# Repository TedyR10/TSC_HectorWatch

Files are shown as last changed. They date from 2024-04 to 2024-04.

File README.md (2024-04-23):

**Name: Theodor-Ioan Rolea**

**Group: 333CA**

# Hector Watch

### Description
* This project focuses on creating a smart watch from the ground up using
certain parts provided by the TSC Team. The smart watch has the following
features: 6 axis intertial unit, haptic motor driver, LiPo battery,
USB C, 1.28 inch 240x240p LCD display.

***

### Steps to developing the watch
* 1. Electrical scheme implementation
* 2. PCB design

***

### Electrical scheme implementation
* The provided electrical scheme was implemented using Fusion 360's schematic feature,
then the components were linked to the PCB design.

***

### PCB design
* The PCB design was done using Fusion 360's PCB design feature. The routes were done
manually, routing with 0.3mm for the power lines and 0.127mm for the signal lines. I
decided not to place the test pads in a specific location, but rather place them in
a way that would allow me to fully connect the components.

***

### Final thoughts
* The project was a great experience, as it allowed me to learn how to use Fusion 360's
schematic and PCB design features. I also learned how to properly route the PCB and
how to properly place the components. I am looking forward to the next project.

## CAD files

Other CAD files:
FullDesign_RoleaTheodorIoan_333CA.f3z

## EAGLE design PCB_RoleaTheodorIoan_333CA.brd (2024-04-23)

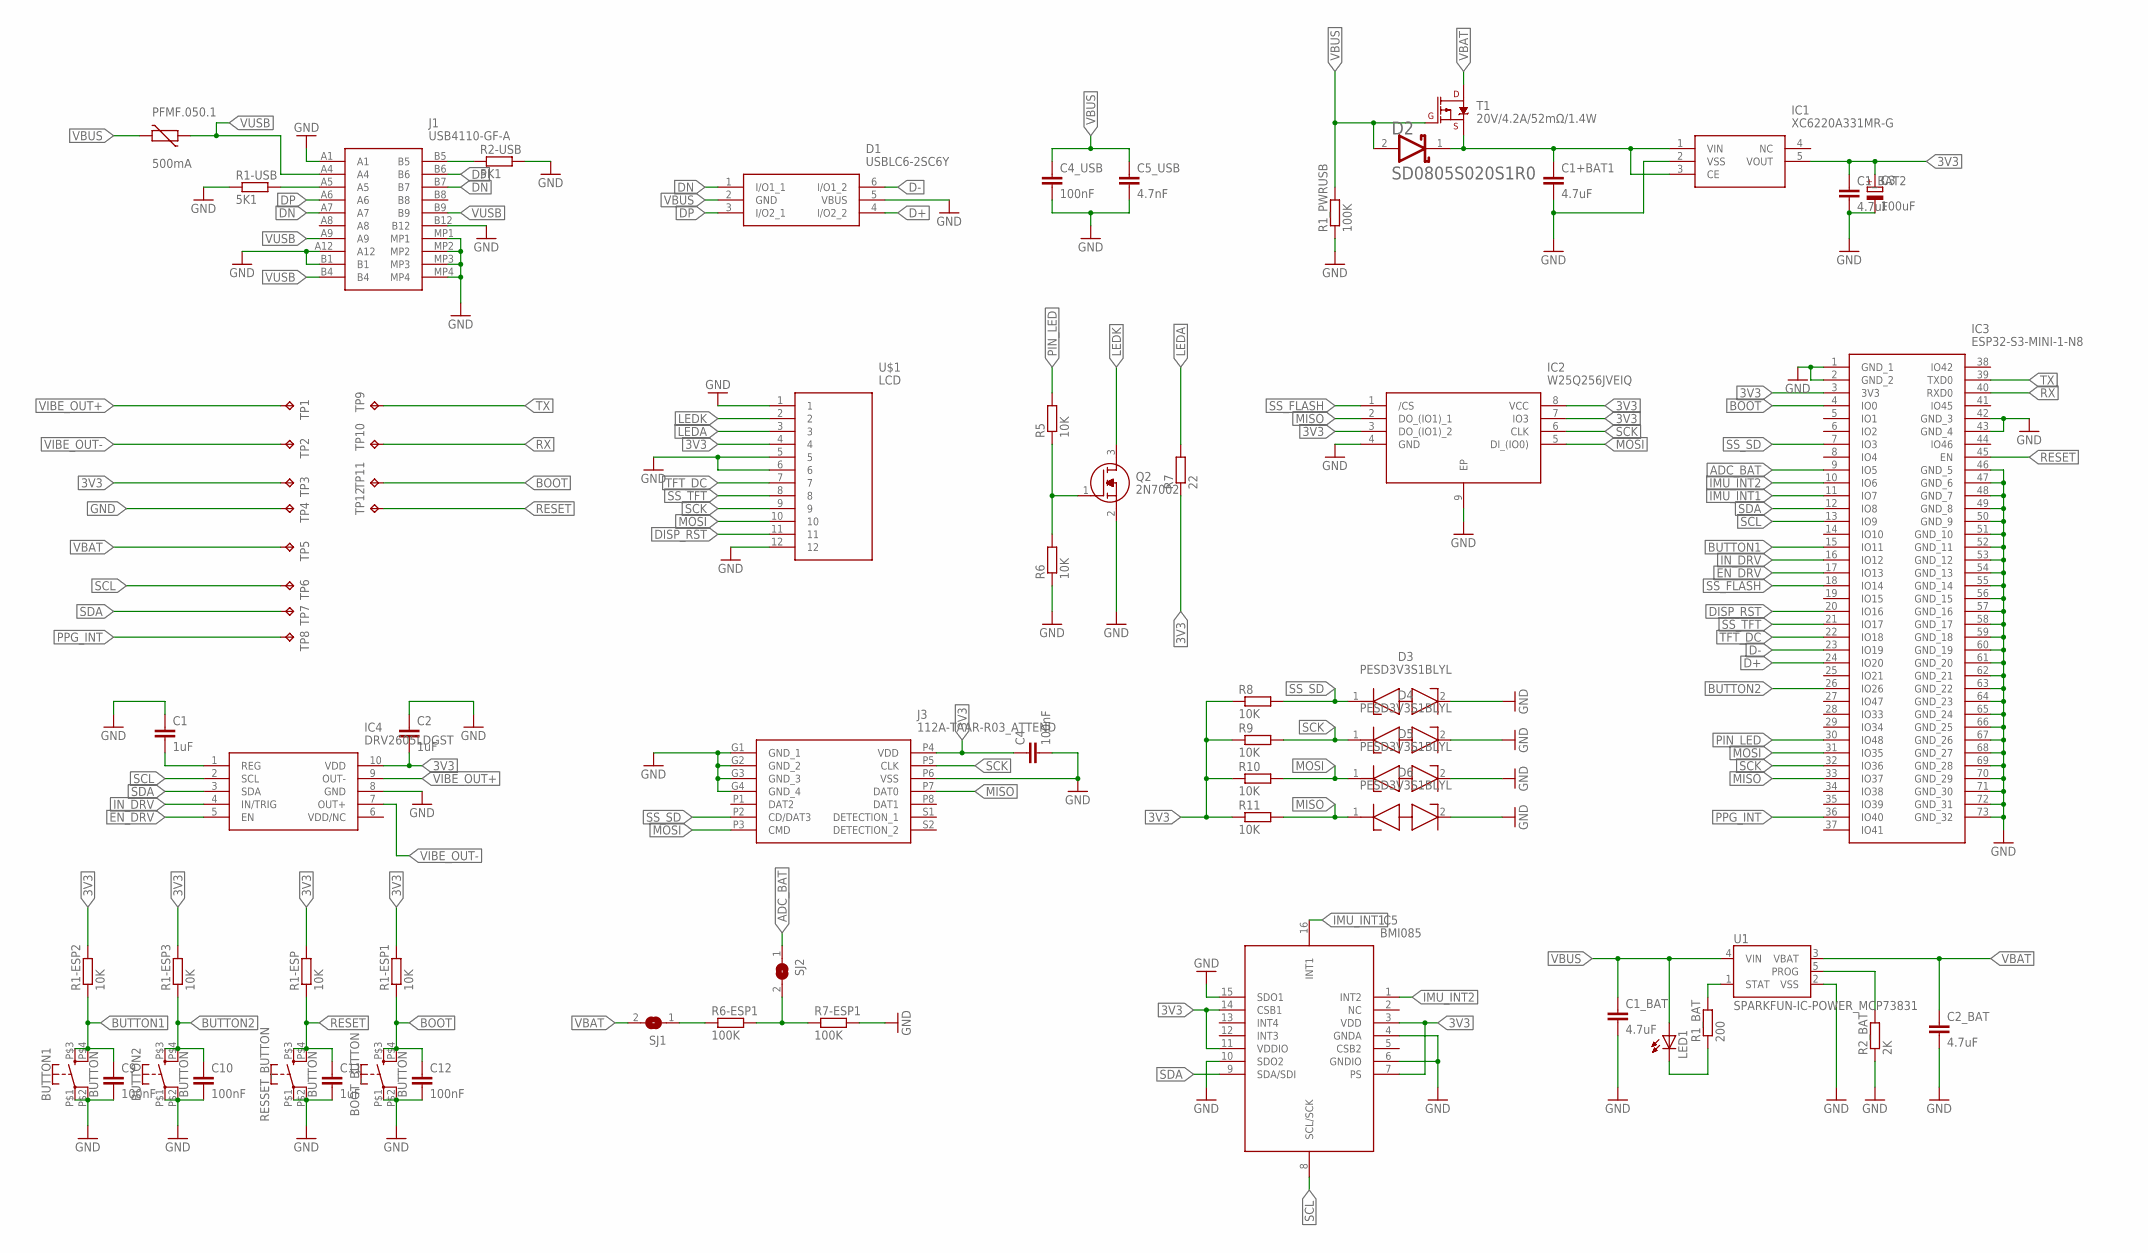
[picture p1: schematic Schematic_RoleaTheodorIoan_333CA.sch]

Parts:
BOOT_BUTTON: BUTTON
BUTTON1, BUTTON2: BUTTON
C1, C2, C11: 1uF; EAGLE-LTSPICE_C0402
C1+BAT1, C1_BAT, C1_BAT2, C2_BAT: 4.7uF; RCL_C0603
C3: 100uF; CT3528
C4, C9, C10, C12: 100nF; EAGLE-LTSPICE_C0402
C4_USB: 100nF; RCL_C0603
C5_USB: 4.7nF; RCL_C0603
D1: USBLC6-2SC6Y; SOT95P280X145-6N
D2: AVX---SD0805S020S1R0_AVX_SD0805S020S1R0AVX_SD0805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; AVX---SD0805S020S1R0_AVX_SD0805S020S1R0_0
D3, D4, D5, D6: PESD3V3S1BLYL; PESD5V0S1BL315
IC1: XC6220A331MR-G; SOT95P280X120-5N
IC2: W25Q256JVEIQ; SON127P800X600X80-9N
IC3: ESP32-S3-MINI-1-N8; ESP32S3MINI1N8
IC4: DRV2605LDGST; SOP50P490X110-10N
IC5: BMI085
J1: USB4110-GF-A; USB4110GFA
J3: 112A-TAAR-R03_ATTEND; 112ATAARR03ATTEND
LED1: ADAFRUIT_LEDCHIP-LED0603; ADAFRUIT_CHIP-LED0603
PFMF.050.1: 500mA; VARISTOR_CT/CN1812
Q2: 2N7002; SOT96P240X120-3N
R1-ESP, R1-ESP1, R1-ESP2, R1-ESP3, R5, R6, R8, R9, R10, R11: 10K; EAGLE-LTSPICE_R0402
R1-USB, R2-USB: 5K1; EAGLE-LTSPICE_R0402
R1_BAT: 200; EAGLE-LTSPICE_R0402
R1_PWRUSB, R6-ESP1, R7-ESP1: 100K; EAGLE-LTSPICE_R0402
R2_BAT: 2K; EAGLE-LTSPICE_R0402
R7: 22; EAGLE-LTSPICE_R0402
RESSET_BUTTON: BUTTON
SJ1, SJ2: SJ
T1: 20V/4.2A/52mΩ/1.4W; SPARKFUN-DISCRETESEMI_SOT23-3
TP1, TP2, TP3, TP4, TP5, TP6, TP7, TP8, TP9, TP10, TP11, TP12: TPTP20R; TP20R
U1: SPARKFUN-IC-POWER_MCP73831; SPARKFUN-IC-POWER_SOT23-5
U$1: LCD; LCD_CONNECTOR

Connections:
3V3: C1_BAT2.1, C2.2, C3.+, C4.1, IC1.5 (VOUT), IC2.3 (DO_(IO1)_2), IC2.7 (IO3), IC2.8 (VCC), IC3.3 (3V3), IC4.10 (VDD), IC5.3 (VDD), IC5.7 (PS), IC5.11 (VDDIO), IC5.14 (CSB1), J3.P4 (VDD), R1-ESP.2, R1-ESP1.2, R1-ESP2.2, R1-ESP3.2, R7.1, R8.1, R9.1, R10.1, R11.1, TP3.TP, U$1.4
ADC_BAT: IC3.9 (IO5), SJ2.1
BOOT: BOOT_BUTTON.P$3 (3), BOOT_BUTTON.P$4 (4), C12.1, IC3.4 (IO0), R1-ESP1.1, TP11.TP
BUTTON1: BUTTON1.P$3 (3), BUTTON1.P$4 (4), C9.1, IC3.15 (IO11), R1-ESP2.1
BUTTON2: BUTTON2.P$3 (3), BUTTON2.P$4 (4), C10.1, IC3.26 (IO26), R1-ESP3.1
D+: D1.4 (I/O2_2), IC3.24 (IO20)
D-: D1.6 (I/O1_2), IC3.23 (IO19)
DISP_RST: IC3.20 (IO16), U$1.11
DN: D1.1 (I/O1_1), J1.A7, J1.B7
DP: D1.3 (I/O2_1), J1.A6, J1.B6
EN_DRV: IC3.17 (IO13), IC4.5 (EN)
GND: BOOT_BUTTON.P$1 (1), BOOT_BUTTON.P$2 (2), BUTTON1.P$1 (1), BUTTON1.P$2 (2), BUTTON2.P$1 (1), BUTTON2.P$2 (2), C1.1, C1+BAT1.2, C1_BAT.2, C1_BAT2.2, C2.1, C2_BAT.2, C3.-, C4.2, C4_USB.2, C5_USB.2, C9.2, C10.2, C11.2, C12.2, D1.5 (VBUS), D3.2 (K2), D4.2 (K2), D5.2 (K2), D6.2 (K2), IC1.2 (VSS), IC2.4 (GND), IC2.9 (EP), IC3.1 (GND_1), IC3.2 (GND_2), IC3.42 (GND_3), IC3.43 (GND_4), IC3.46 (GND_5), IC3.47 (GND_6), IC3.48 (GND_7), IC3.49 (GND_8), IC3.50 (GND_9), IC3.51 (GND_10), IC3.52 (GND_11), IC3.53 (GND_12), IC3.54 (GND_13), IC3.55 (GND_14), IC3.56 (GND_15), IC3.57 (GND_16), IC3.58 (GND_17), IC3.59 (GND_18), IC3.60 (GND_19), IC3.61 (GND_20), IC3.62 (GND_21), IC3.63 (GND_22), IC3.64 (GND_23), IC3.65 (GND_24), IC3.66 (GND_25), IC3.67 (GND_26), IC3.68 (GND_27), IC3.69 (GND_28), IC3.70 (GND_29), IC3.71 (GND_30), IC3.72 (GND_31), IC3.73 (GND_32), IC4.8 (GND), IC5.4 (GNDA), IC5.6 (GNDIO), IC5.10 (SDO2), IC5.15 (SDO1), J1.A1, J1.A12, J1.B1, J1.B12, J1.MP1, J1.MP2, J1.MP3, J1.MP4, J3.G1 (GND_1), J3.G2 (GND_2), J3.G3 (GND_3), J3.G4 (GND_4), J3.P6 (VSS), Q2.2 (S), R1-USB.1, R1_PWRUSB.1, R2-USB.2, R2_BAT.1, R6.1, R7-ESP1.2, RESSET_BUTTON.P$1 (1), RESSET_BUTTON.P$2 (2), TP4.TP, U1.2 (VSS), U$1.1, U$1.5, U$1.6, U$1.12
IMU_INT1: IC3.11 (IO7), IC5.16 (INT1)
IMU_INT2: IC3.10 (IO6), IC5.1 (INT2)
IN_DRV: IC3.16 (IO12), IC4.4 (IN/TRIG)
LEDA: R7.2, U$1.3
LEDK: Q2.3 (D), U$1.2
MISO: D6.1 (K1), IC2.2 (DO_(IO1)_1), IC3.33 (IO37), J3.P7 (DAT0), R11.2
MOSI: D5.1 (K1), IC2.5 (DI_(IO0)), IC3.31 (IO35), J3.P3 (CMD), R10.2, U$1.10
unnamed: J1.B5, R2-USB.1
unnamed: R6-ESP1.1, SJ1.1
unnamed: C1+BAT1.1, D2.1 (CATHODE), IC1.1 (VIN), IC1.3 (CE), T1.2 (S)
unnamed: C1.2, IC4.1 (REG)
unnamed: Q2.1 (G), R5.1, R6.2
unnamed: R6-ESP1.2, R7-ESP1.1, SJ2.2
unnamed: R1_BAT.2, U1.1 (STAT)
unnamed: R2_BAT.2, U1.5 (PROG)
unnamed: J1.A5, R1-USB.2
unnamed: LED1.C, R1_BAT.1
PIN_LED: IC3.30 (IO48), R5.2
PPG_INT: IC3.36 (IO40), TP8.TP
RESET: C11.1, IC3.45 (EN), R1-ESP.1, RESSET_BUTTON.P$3 (3), RESSET_BUTTON.P$4 (4), TP12.TP
RX: IC3.40 (RXD0), TP10.TP
SCK: D4.1 (K1), IC2.6 (CLK), IC3.32 (IO36), J3.P5 (CLK), R9.2, U$1.9
SCL: IC3.13 (IO9), IC4.2 (SCL), IC5.8 (SCL/SCK), TP6.TP
SDA: IC3.12 (IO8), IC4.3 (SDA), IC5.9 (SDA/SDI), TP7.TP
SS_FLASH: IC2.1 (/CS), IC3.18 (IO14)
SS_SD: D3.1 (K1), IC3.7 (IO3), J3.P2 (CD/DAT3), R8.2
SS_TFT: IC3.21 (IO17), U$1.8
TFT_DC: IC3.22 (IO18), U$1.7
TX: IC3.39 (TXD0), TP9.TP
VBAT: C2_BAT.1, SJ1.2, T1.3 (D), TP5.TP, U1.3 (VBAT)
VBUS: C1_BAT.1, C4_USB.1, C5_USB.1, D1.2 (GND), D2.2 (ANODE), LED1.A, PFMF.050.1.2, R1_PWRUSB.2, T1.1 (G), U1.4 (VIN)
VIBE_OUT+: IC4.9 (OUT-), TP1.TP
VIBE_OUT-: IC4.7 (OUT+), TP2.TP
VUSB: J1.A4, J1.A9, J1.B4, J1.B9, PFMF.050.1.1

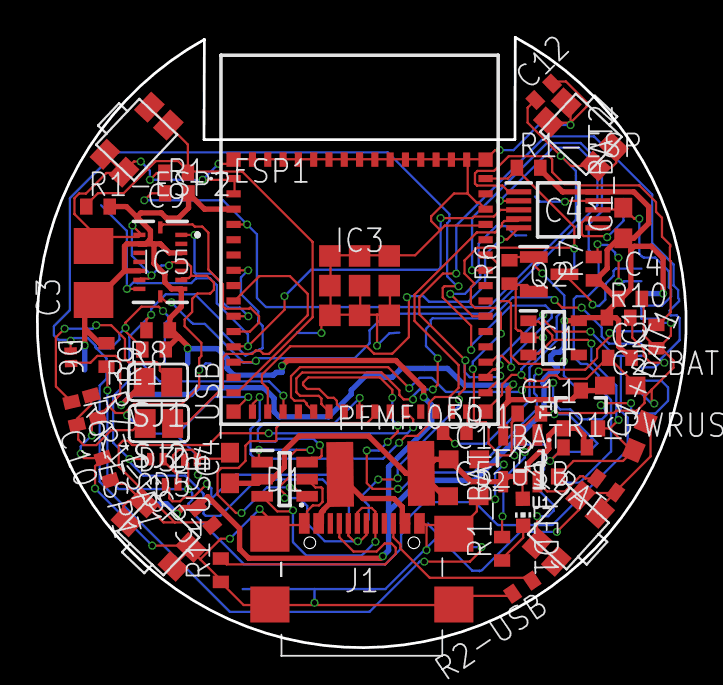
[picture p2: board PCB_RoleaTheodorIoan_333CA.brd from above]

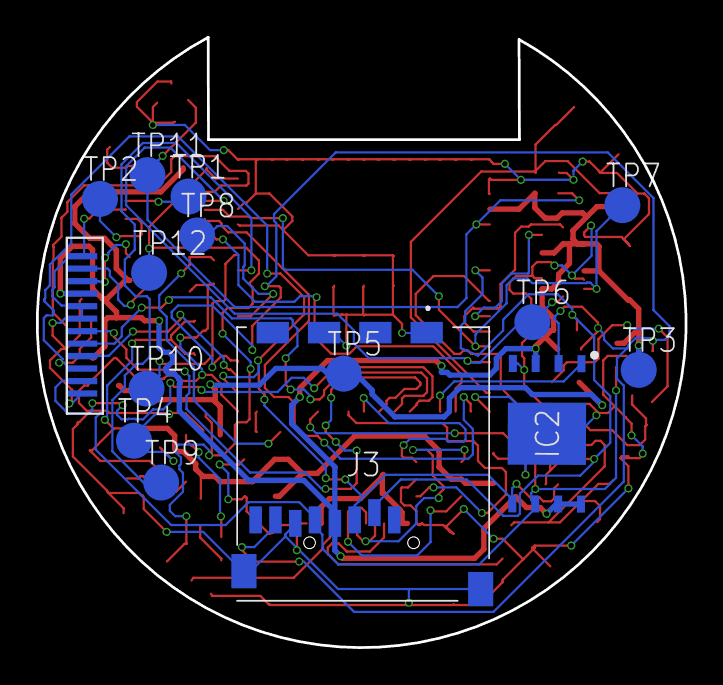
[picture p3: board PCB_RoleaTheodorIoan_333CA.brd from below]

Board: 2 copper layers, 36.0 x 33.9 mm, 69 parts (15 on the bottom side), 46 nets.
